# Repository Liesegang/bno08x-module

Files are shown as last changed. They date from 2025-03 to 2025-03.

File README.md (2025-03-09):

# BNO08x module

Akizuki [BNO055使用 9軸センサーフュージョンモジュールキット](https://akizukidenshi.com/catalog/g/g116996/) compatible BNO08x module board.
[BNO08x datasheet](https://www.ceva-ip.com/wp-content/uploads/BNO080_085-Datasheet.pdf)

**SUPPORT 3.3V ONLY**
Support qwiic connector.

|Solde Jumper|Function|
|--|--|
|J1|PS0 Low|
|J2|PS0 High|
|J3|PS1 Low|
|J4|PS1 High|
|J5|I2C Addr High|
|J6|I2C Addr LOW|

## Mode

|J1|J2|J3|J4|Mode|
|--|--|--|--|--|
|closed|open|closed|open|I2C|
|open|closed|closed|open|UART|

## I2C Addr

|JP5|JP6|I2C Addr|
|--|--|--|
|open|open|undefined|
|open|close|0x4A|
|close|open|0x4B|
|close|close|SHORT VCC AND GND!!!!!|





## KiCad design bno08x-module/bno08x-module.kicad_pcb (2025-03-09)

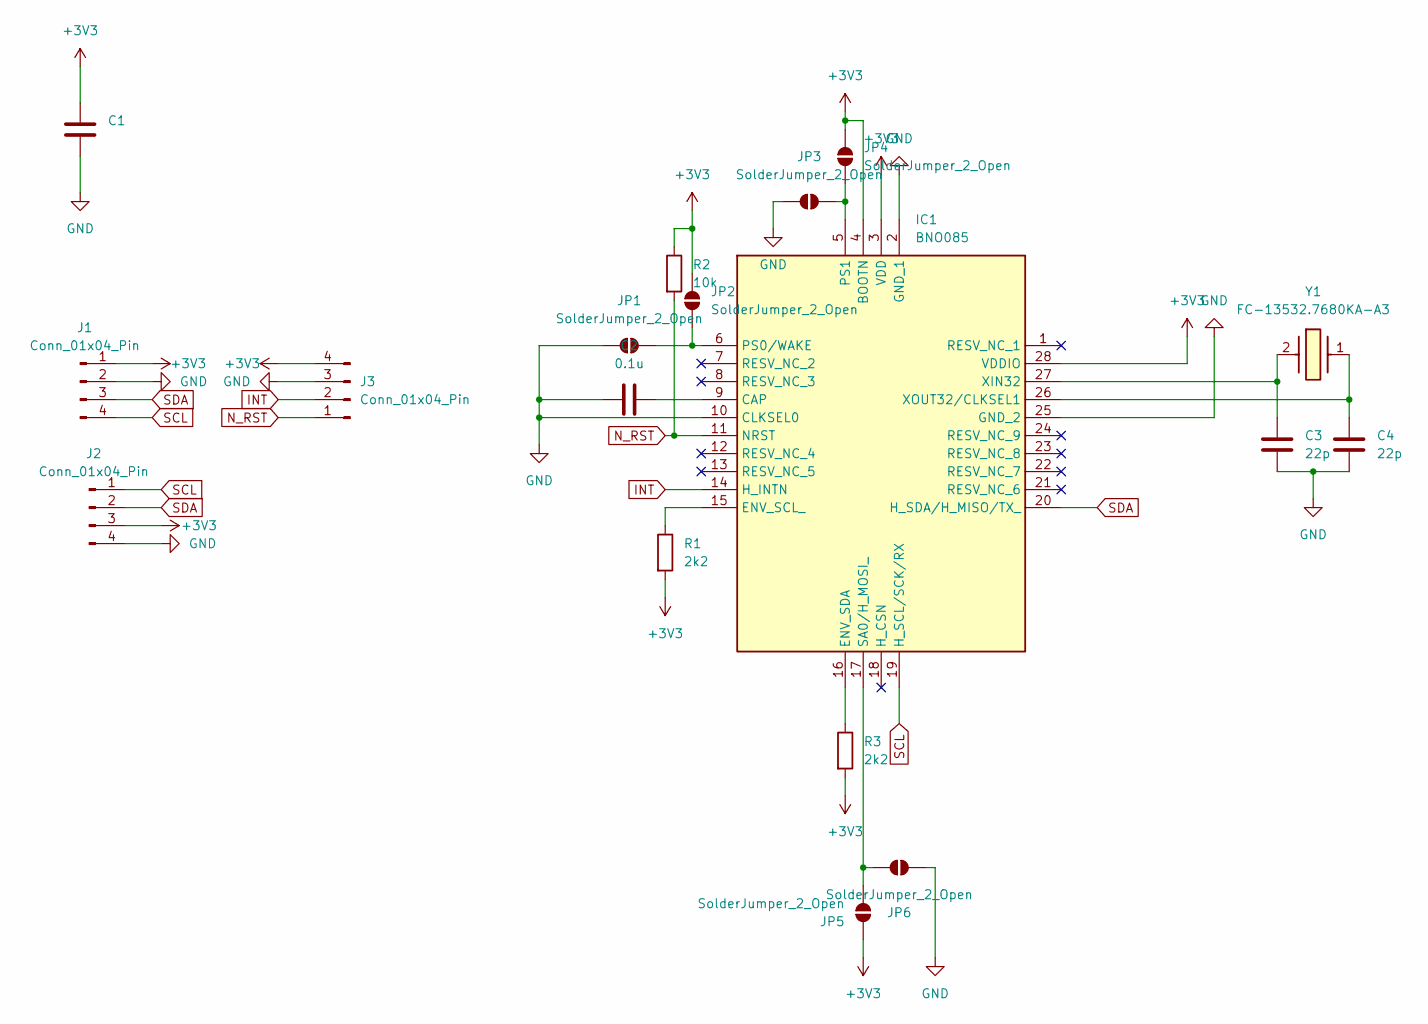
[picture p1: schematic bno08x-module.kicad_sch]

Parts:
C1, C2: 0.1u; C_0603_1608Metric
C3, C4: 22p; C_0603_1608Metric
IC1: BNO085; Manufacturer_Part_Number BNO085; Mouser Part Number 526-BNO085
J1, J3: Conn_01x04_Pin; PinHeader_1x04_P2.54mm_Vertical
J2: Conn_01x04_Pin; JST_SH_BM04B-SRSS-TB_1x04-1MP_P1.00mm_Vertical
JP1, JP2, JP3, JP4, JP5, JP6: SolderJumper_2_Open; R_0201_0603Metric
R1, R3: 2k2; R_0603_1608Metric
R2: 10k; R_0603_1608Metric
Y1: FC-13532.7680KA-A3; FC135327680KAA3; Manufacturer_Part_Number FC-13532.7680KA-A3

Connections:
+3V3: C1.1, IC1.3 (VDD), IC1.4 (BOOTN), IC1.28 (VDDIO), J1.1, J2.3, J3.4, JP2.2 (B), JP4.2 (B), JP5.2 (B), R1.2, R2.1, R3.2
GND: C1.2, C2.1, C3.2, C4.2, IC1.2 (GND_1), IC1.10 (CLKSEL0), IC1.25 (GND_2), J1.2, J2.4, J3.3, JP1.1 (A), JP3.1 (A), JP6.1 (A)
INT: IC1.14 (H_INTN), J3.2
N_RST: IC1.11 (NRST), J3.1, R2.2
unnamed: C2.2, IC1.9 (CAP)
unnamed: IC1.15 (ENV_SCL_), R1.1
unnamed: IC1.16 (ENV_SDA), R3.1
unnamed: IC1.6 (PS0/WAKE), JP1.2 (B), JP2.1 (A)
unnamed: IC1.5 (PS1), JP3.2 (B), JP4.1 (A)
unnamed: IC1.17 (SA0/H_MOSI_), JP5.1 (A), JP6.2 (B)
unnamed: C3.1, IC1.27 (XIN32), Y1.2 (CRYSTAL_2)
unnamed: C4.1, IC1.26 (XOUT32/CLKSEL1), Y1.1
SCL: IC1.19 (H_SCL/SCK/RX), J1.4, J2.1
SDA: IC1.20 (H_SDA/H_MISO/TX_), J1.3, J2.2

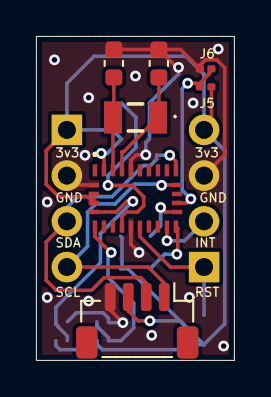
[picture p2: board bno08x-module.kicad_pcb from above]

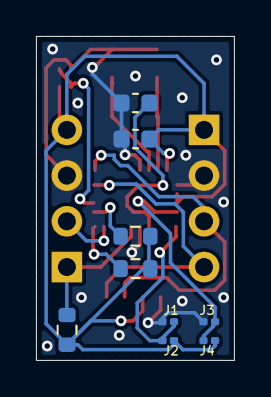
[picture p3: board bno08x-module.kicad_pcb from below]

Board: 2 copper layers, 11.0 x 18.0 mm, 18 parts (11 on the bottom side), 14 nets.
